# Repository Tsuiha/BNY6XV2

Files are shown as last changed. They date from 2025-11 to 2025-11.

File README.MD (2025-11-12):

# BNY6X V2

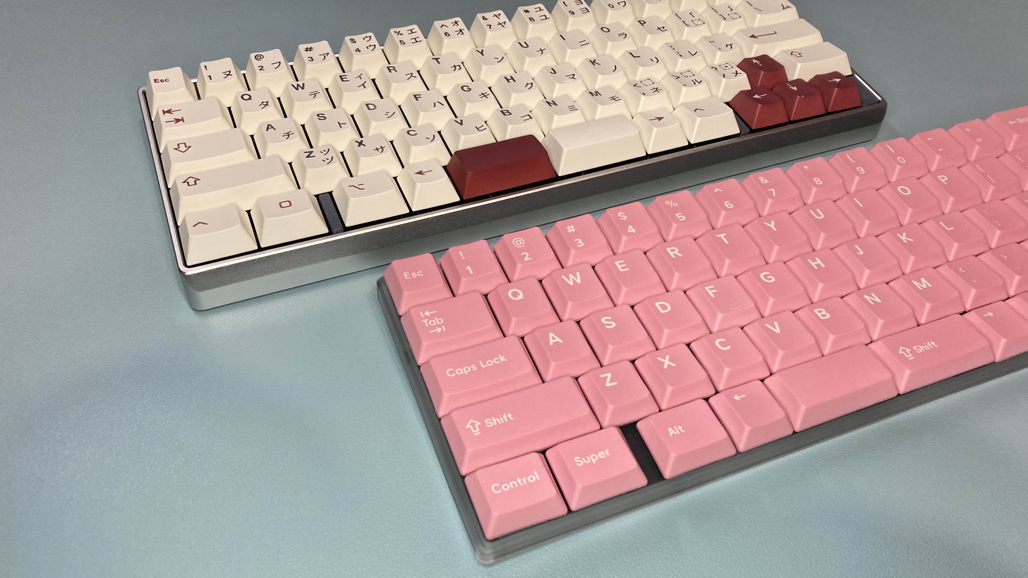
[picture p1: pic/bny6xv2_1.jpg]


「BNY6X V2」は2025年に製作した60%キーボードです。  
多親指キー＋矢印キー配列、MXとロープロに両対応、GH60互換ケース対応、の特徴があります。

---

## BNY6X V2 PCB

- **キー配列**
60%レイアウト  
親指キー、矢印キーを備えた最下行  

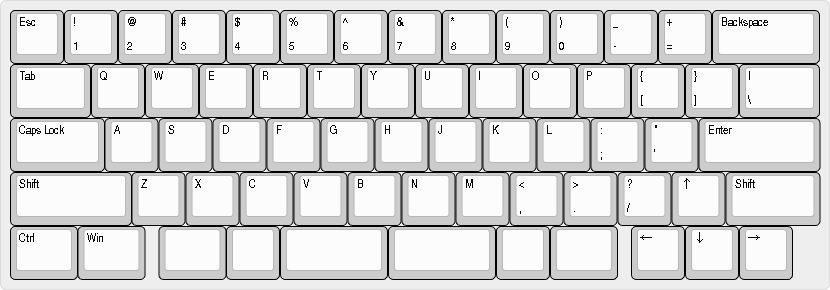
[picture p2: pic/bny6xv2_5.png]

[Keyboard Layout Editor](https://www.keyboard-layout-editor.com/)

- **対応マウント方式**
GH60互換設計で、6か所のネジ穴が設けられています。  
加えて外周に5か所の切り欠きが設けられており、独自のプレートマウントにも対応します。

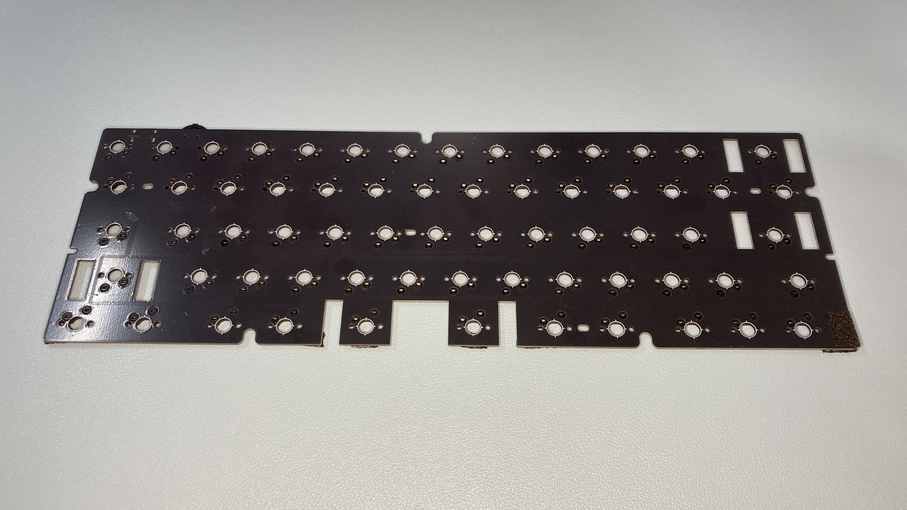
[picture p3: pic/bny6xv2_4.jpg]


- **対応スイッチ**
「Cherry MX 」または「KS-33B GateronLowProfile 3.0」に互換性のあるスイッチが使用できます。  
キースイッチはMX用ホットスワップソケットにてPCBに接続します。
ロープロ対応及び低背化のため基板は1.2mm を使用します。

- **サイドスイッチ**
背面type-C横には3方向（左、右、押し込み）のレバースイッチが取り付け可能です。  
既製品のGH60互換ケースに使用する際は、干渉するためレバースイッチは実装しない必要があります。

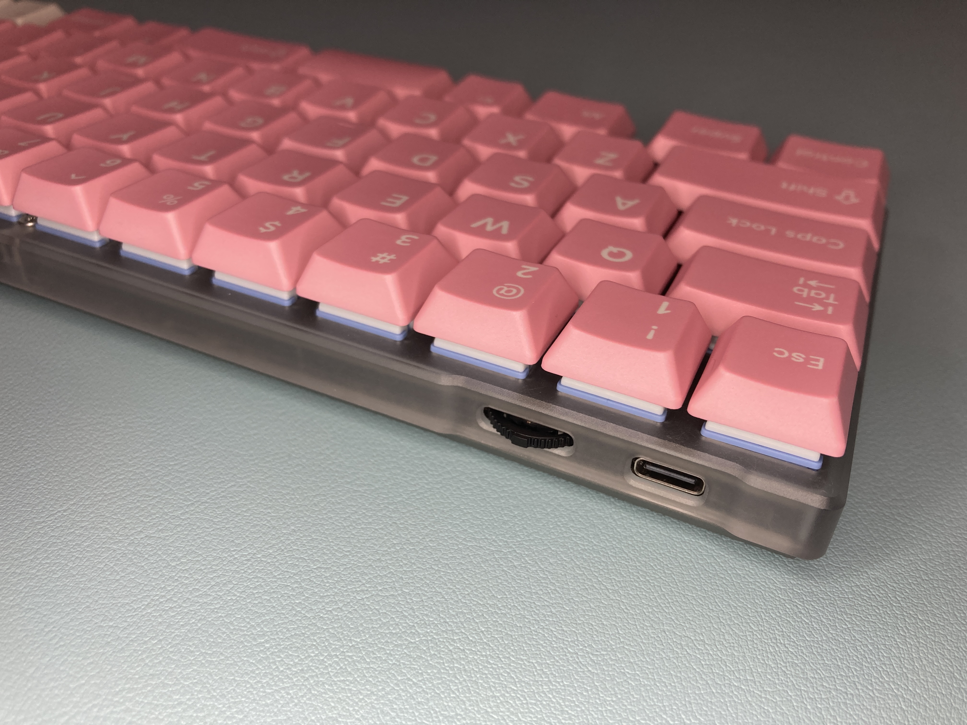
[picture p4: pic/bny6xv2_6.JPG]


- **対応スタビライザー**
プレートマウントのスタビライザーにのみ対応します。  
またMXスイッチの場合スタビライザー下が開いているため、ケース取り付け前に予めスタビライザー部のキーキャップは取り付けておく必要があります。

- **Firmware**
QMK Fimware, [BNY6X V2 codes](https://github.com/Tsuiha/vial-qmk/tree/vial/keyboards/0_tsuiha/bny6x_v2)

---

## BNY6X V2 typeT

1ピースでCNC加工を想定したGH60互換トレイケースです。

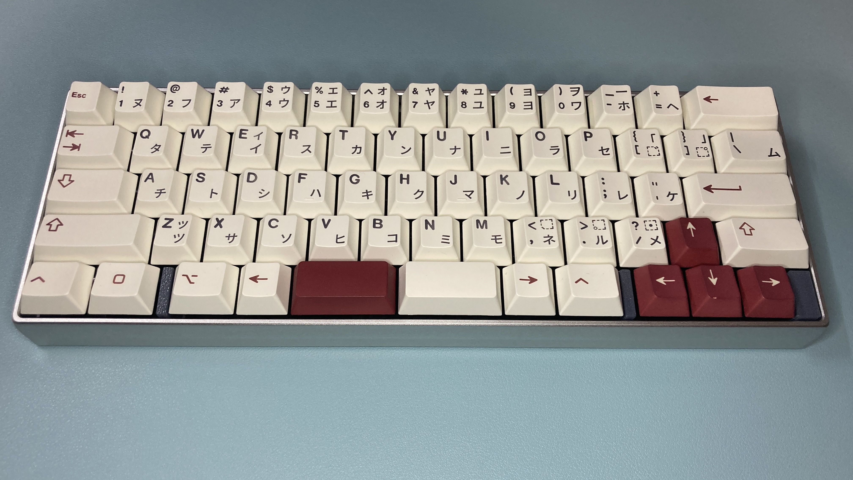
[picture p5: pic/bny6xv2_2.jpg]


- **マウント箇所**
左右4か所のみネジ受けを設けており、中央2か所は省いています。  
ねじ止めで位置を固定し、ボトムフォームで基板を保持する機構です。

- **フロントベゼル幅**
フロントトップのベゼルをカットし幅を抑えています。  
指付け根でのキー入力時に干渉しにくいです。

- **低背設計**
高さを抑えているため、手前部に背の高い実装部品や下付きソケットの基板の場合ケースに干渉する恐れがあります。

- **チルト角**
6度固定です。

- **type-C開口**
上方向に余裕があるため、手前部に基板の干渉がある場合、スタンドオフにスペーサを噛ませることで干渉を回避できます。  
また横方向のtype-C位置はGH60、Wootingの両方に対応します。

---

## BNY6X V2 typeL

BNY6X V2用に設計しました。  
2ピースでCNC加工を想定したKS33-Bスイッチ用のBNY6X V2 PCBケースです。

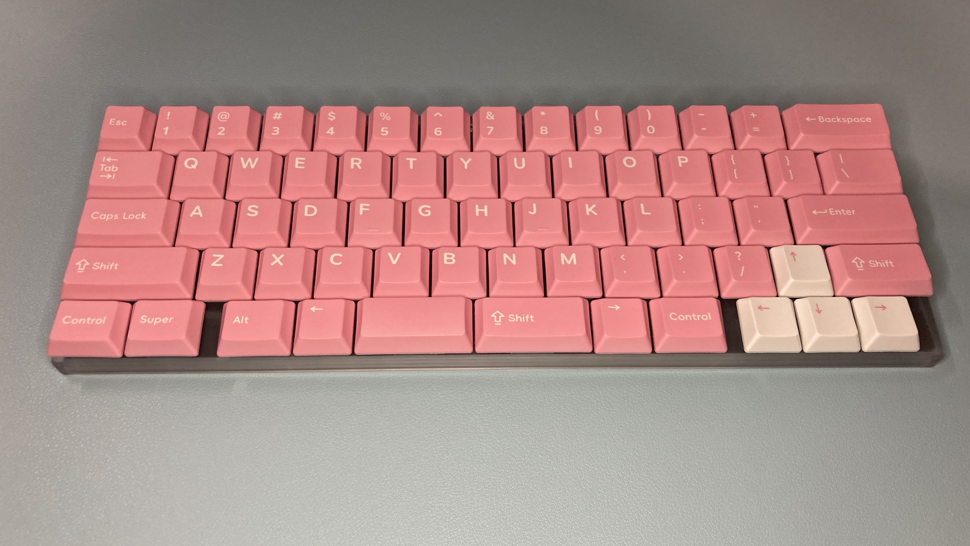
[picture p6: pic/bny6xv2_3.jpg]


- **対応スタビライザー**
Gateron KS-57　ロープロファイルスイッチ用スタビライザーに対応しています。

- **マウント方式**
BNY6X V2 PCBの切り欠き部を介しトップケースとボトムケースとをねじ止めしマウントします。

- **レバースイッチ**
背面はレバースイッチの実装に対応しています。

- **コンパクト設計**
高さとベゼル幅を抑えたコンパクトな外形です。

- **チルト角**
6度固定です。

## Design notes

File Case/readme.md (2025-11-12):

typeT:

 gh60 compatible case

typeL:

 original case for bny6x v2 with KS-33B switches

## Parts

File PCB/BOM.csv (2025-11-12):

bom | specification example of supplier
J1 | typeC receptacle topmount 16+8pins GCT USB4105-GF-A
U1 | STM STM32F072CBT6
U2 | onsemi CM1293A-04SO
U3 | 3.3V LDO SOT23 TI TLV77133PDBVR
side switch | sp3t TMHU27 Akitsukidenshi
boot switch | C&K spst pts526
C1,C3 | 1uF Capacitor 0603(1608m)
C2 | 4.7uF Capacitor 0603(1608m)
C4-C7 | 0.1uF Capacitor 0603(1608m)
R1,R2 | 5.1kohm Resistor 0603(1608m)
R3 | 10kohm Resistor 0603(1608m)

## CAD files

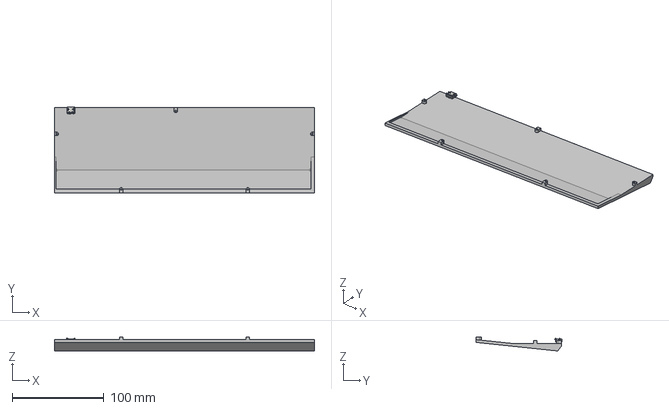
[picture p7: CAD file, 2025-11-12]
Case/typeL/bny6xv2_typeL_bot.step
283.4 x 93.9 x 15.2 mm

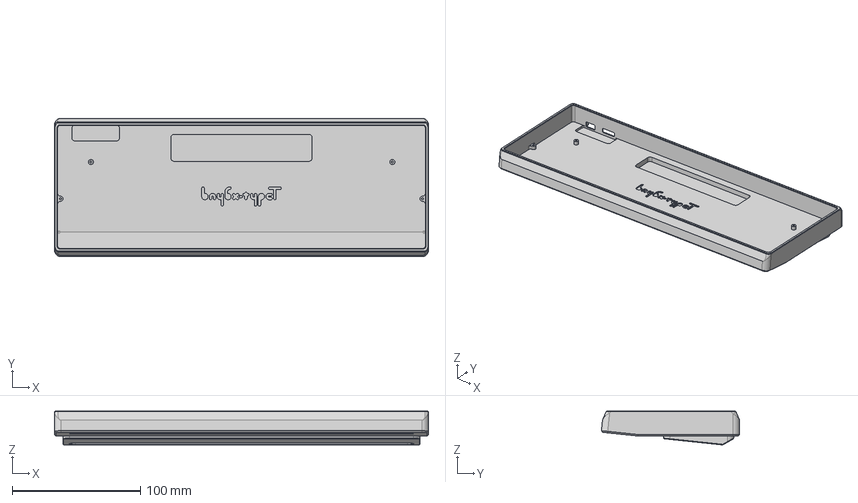
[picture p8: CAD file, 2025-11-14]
Case/typeT/bny6xv2_typeT_lever.step
291.3 x 107.7 x 26.5 mm

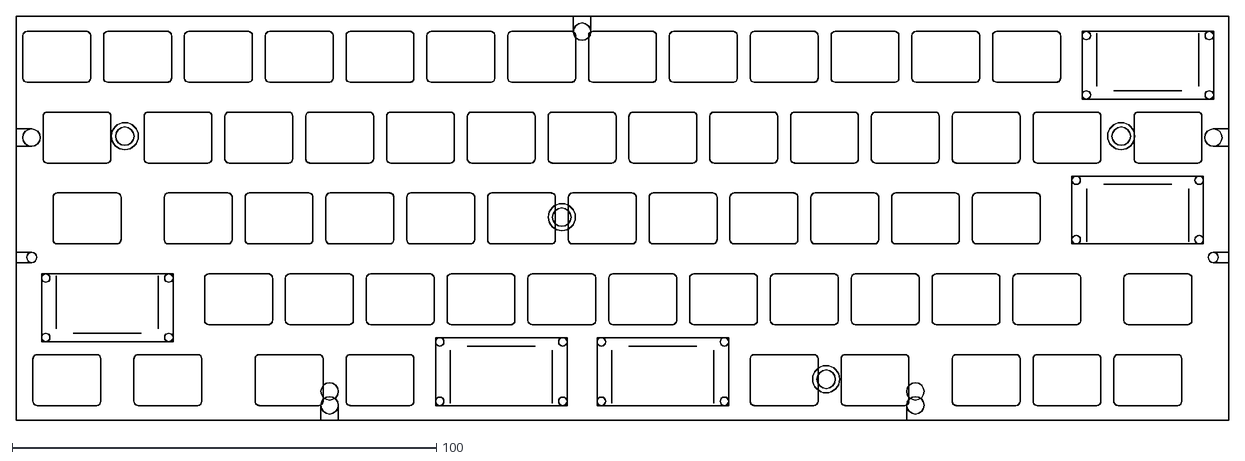
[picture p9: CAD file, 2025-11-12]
Plate/LP/bny6x2lp_plt_carvline.dxf
285.8 x 95.3

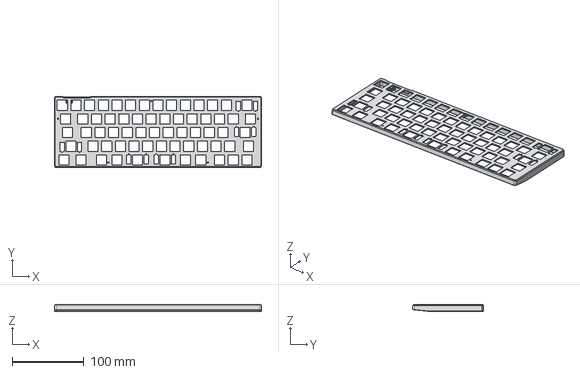
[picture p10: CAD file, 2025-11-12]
Case/typeL/bny6xv2_typeL_top.step
288.4 x 99.2 x 9.50 mm

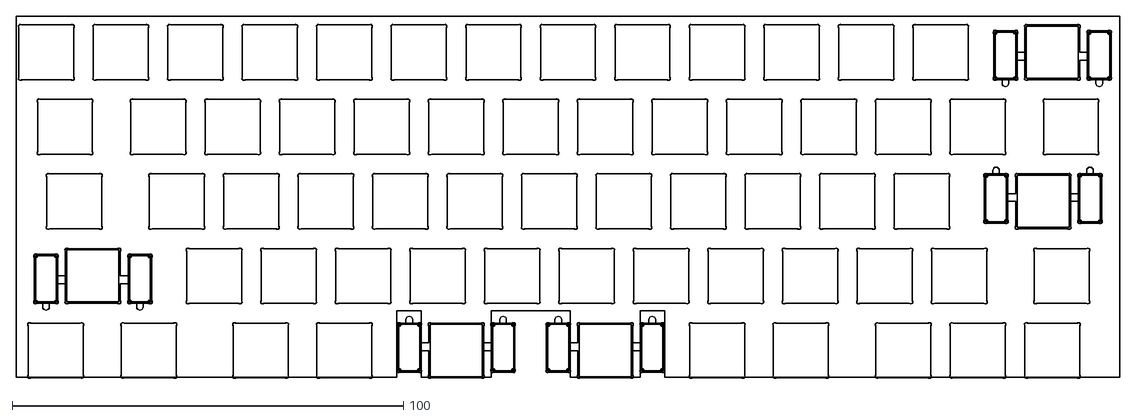
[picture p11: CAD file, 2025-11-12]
Plate/LP/bny6x2lp_plt_outline.dxf
282.2 x 92.6

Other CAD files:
Case/typeT/bny6xv2_typeT_gh60.step
Case/typeL/bny6xv2_typeL.f3d
Case/typeT/bny6xv2_typeT_gh60.f3d

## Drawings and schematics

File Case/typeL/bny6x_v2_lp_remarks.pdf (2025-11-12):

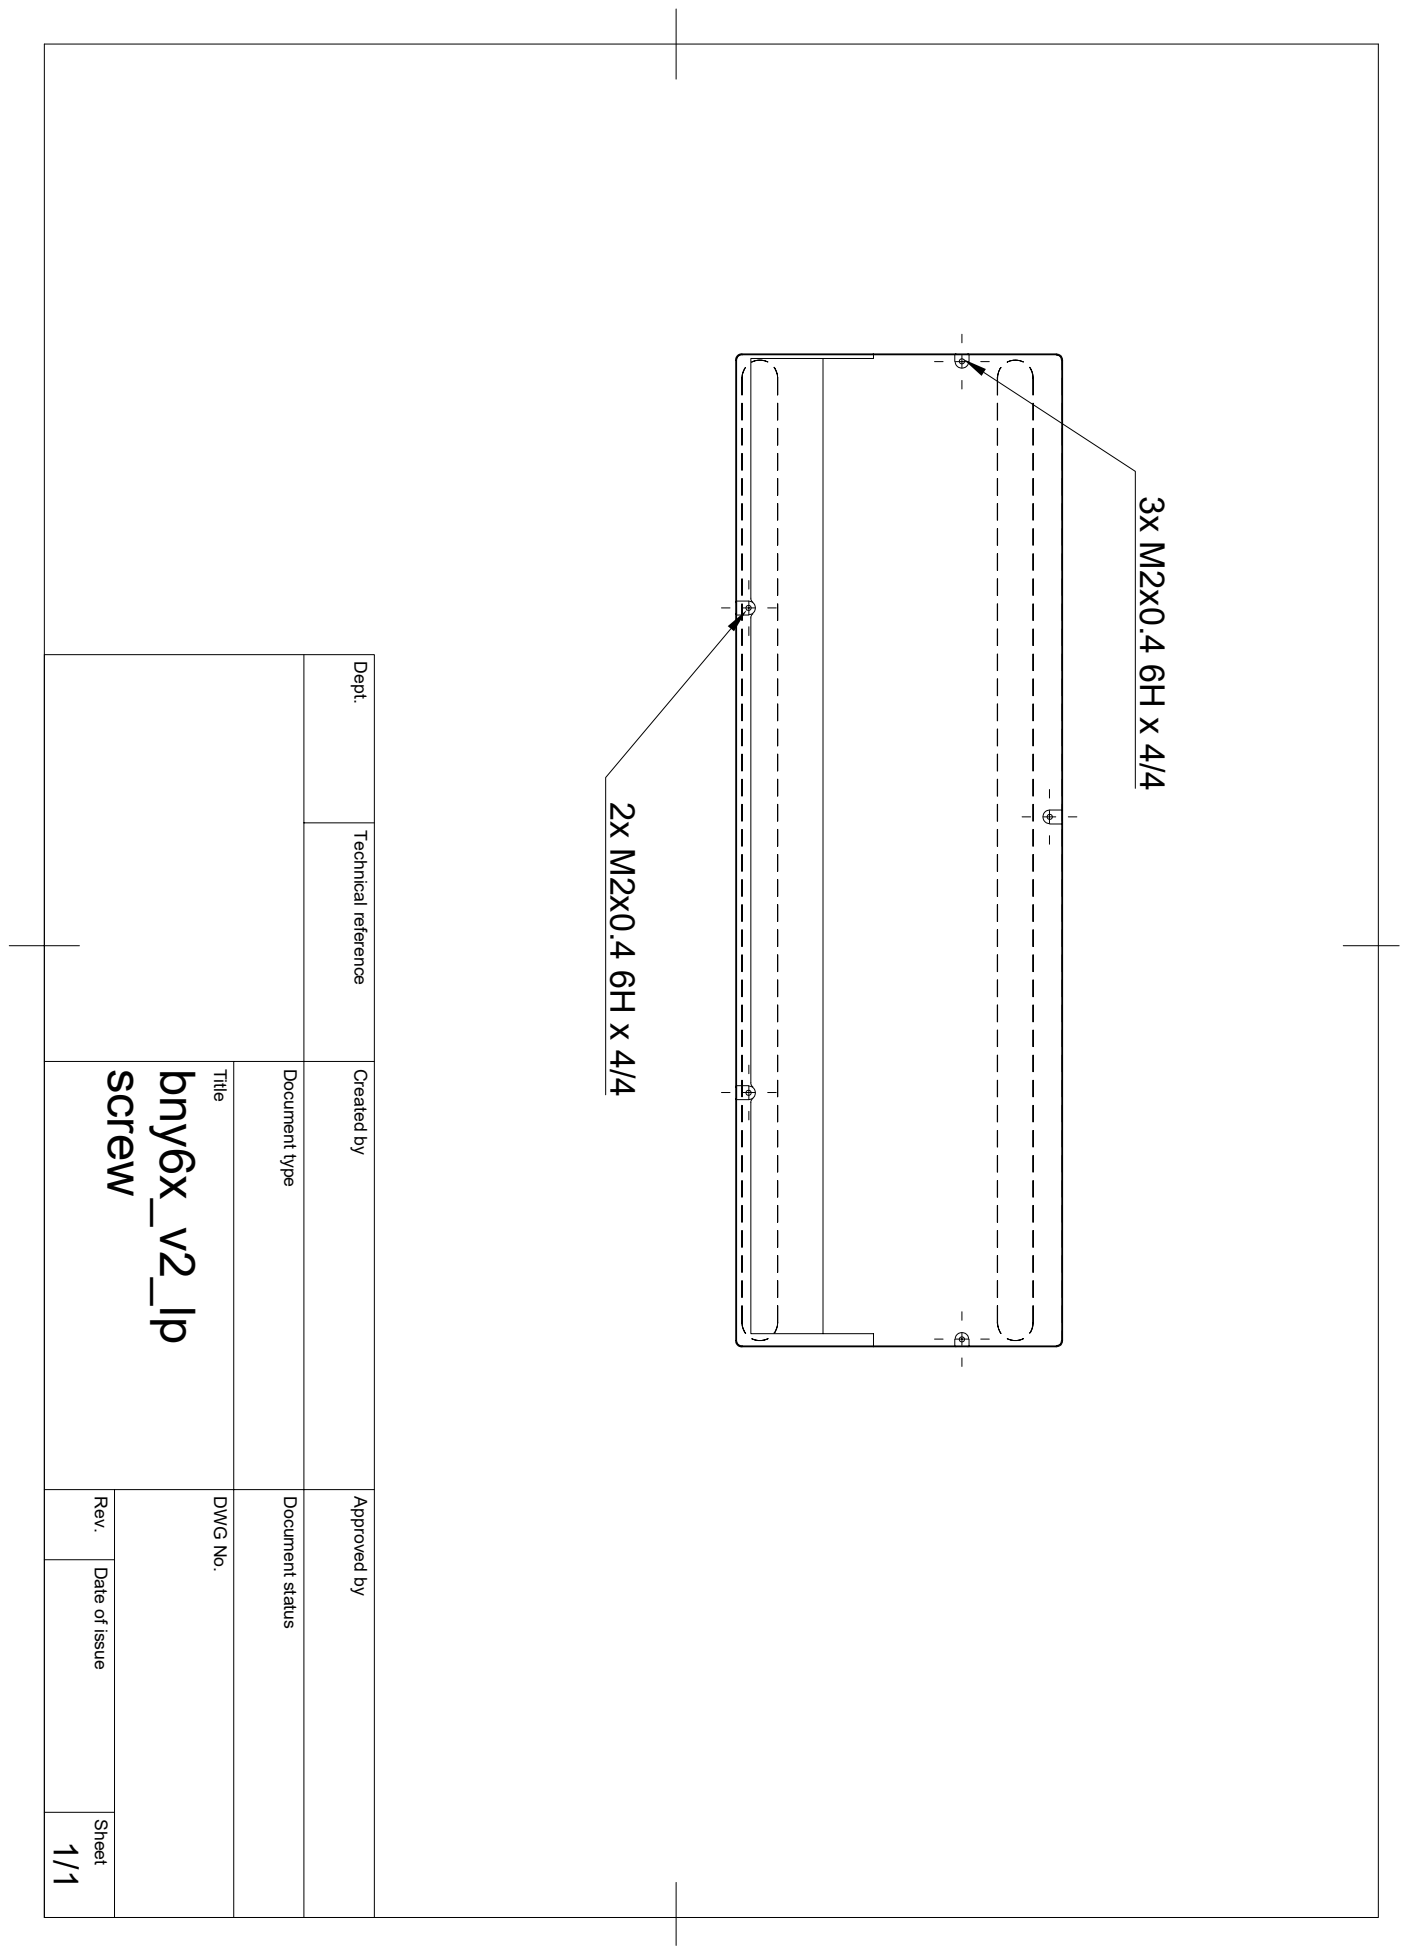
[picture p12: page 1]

Dept. Technical reference Created by Approved by Title DWG No. Document type Document status Rev. Date of issue Sheet 1/1 screw bny6x_v2_lp 3x M2x0.4 6H x 4/4 2x M2x0.4 6H x 4/4

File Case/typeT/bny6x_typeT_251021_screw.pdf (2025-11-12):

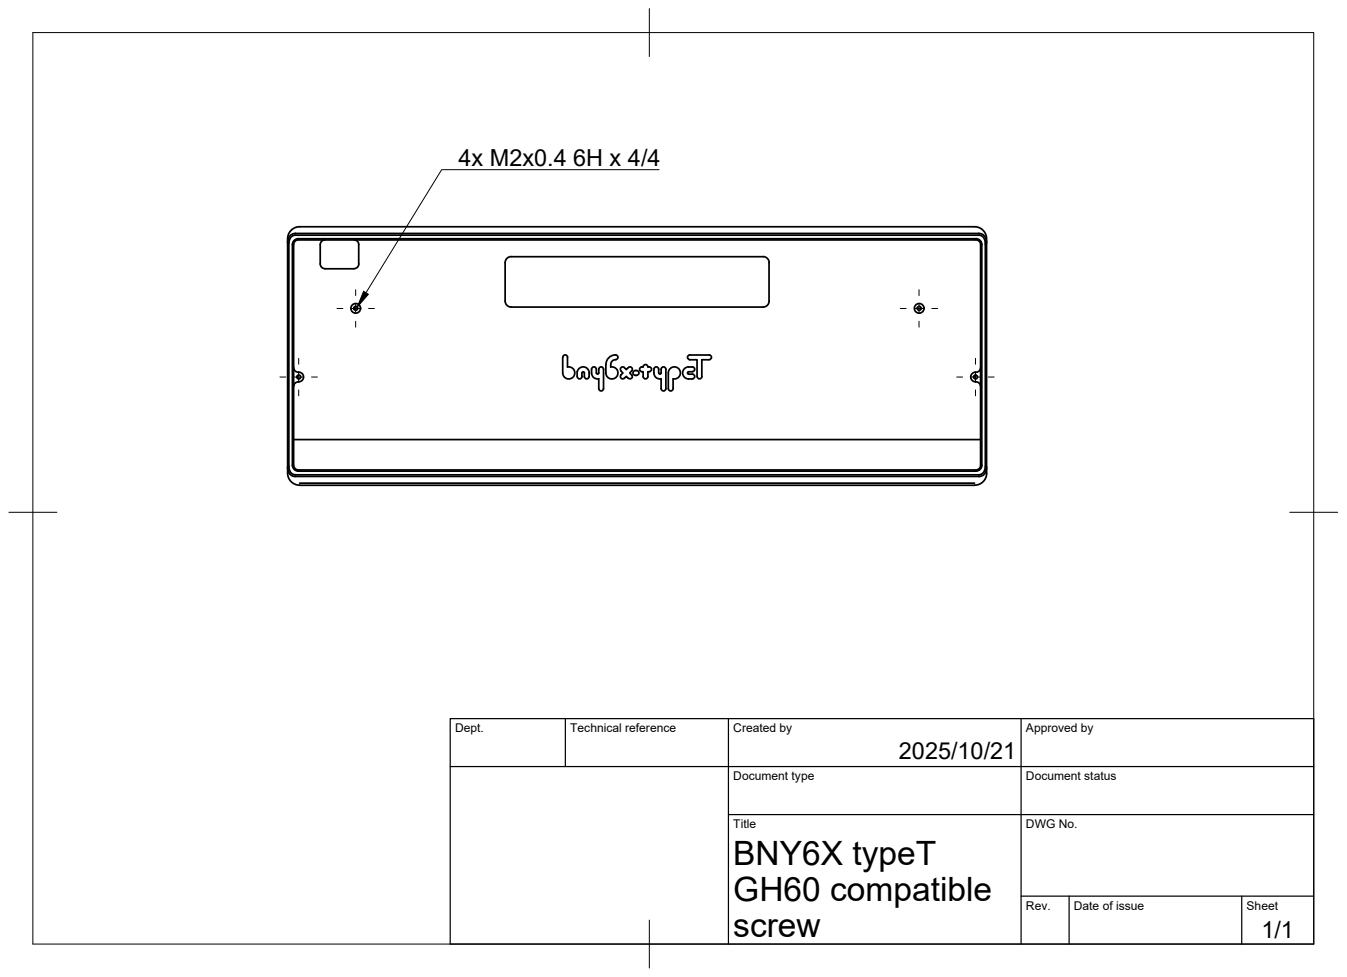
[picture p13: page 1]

Dept. | Technical reference | Created by 2025/10/21 | Approved by

Document type | Document status

Title BNY6X typeT GH60 compatible screw | DWG No.

Rev. | Date of issue | Sheet 1/1

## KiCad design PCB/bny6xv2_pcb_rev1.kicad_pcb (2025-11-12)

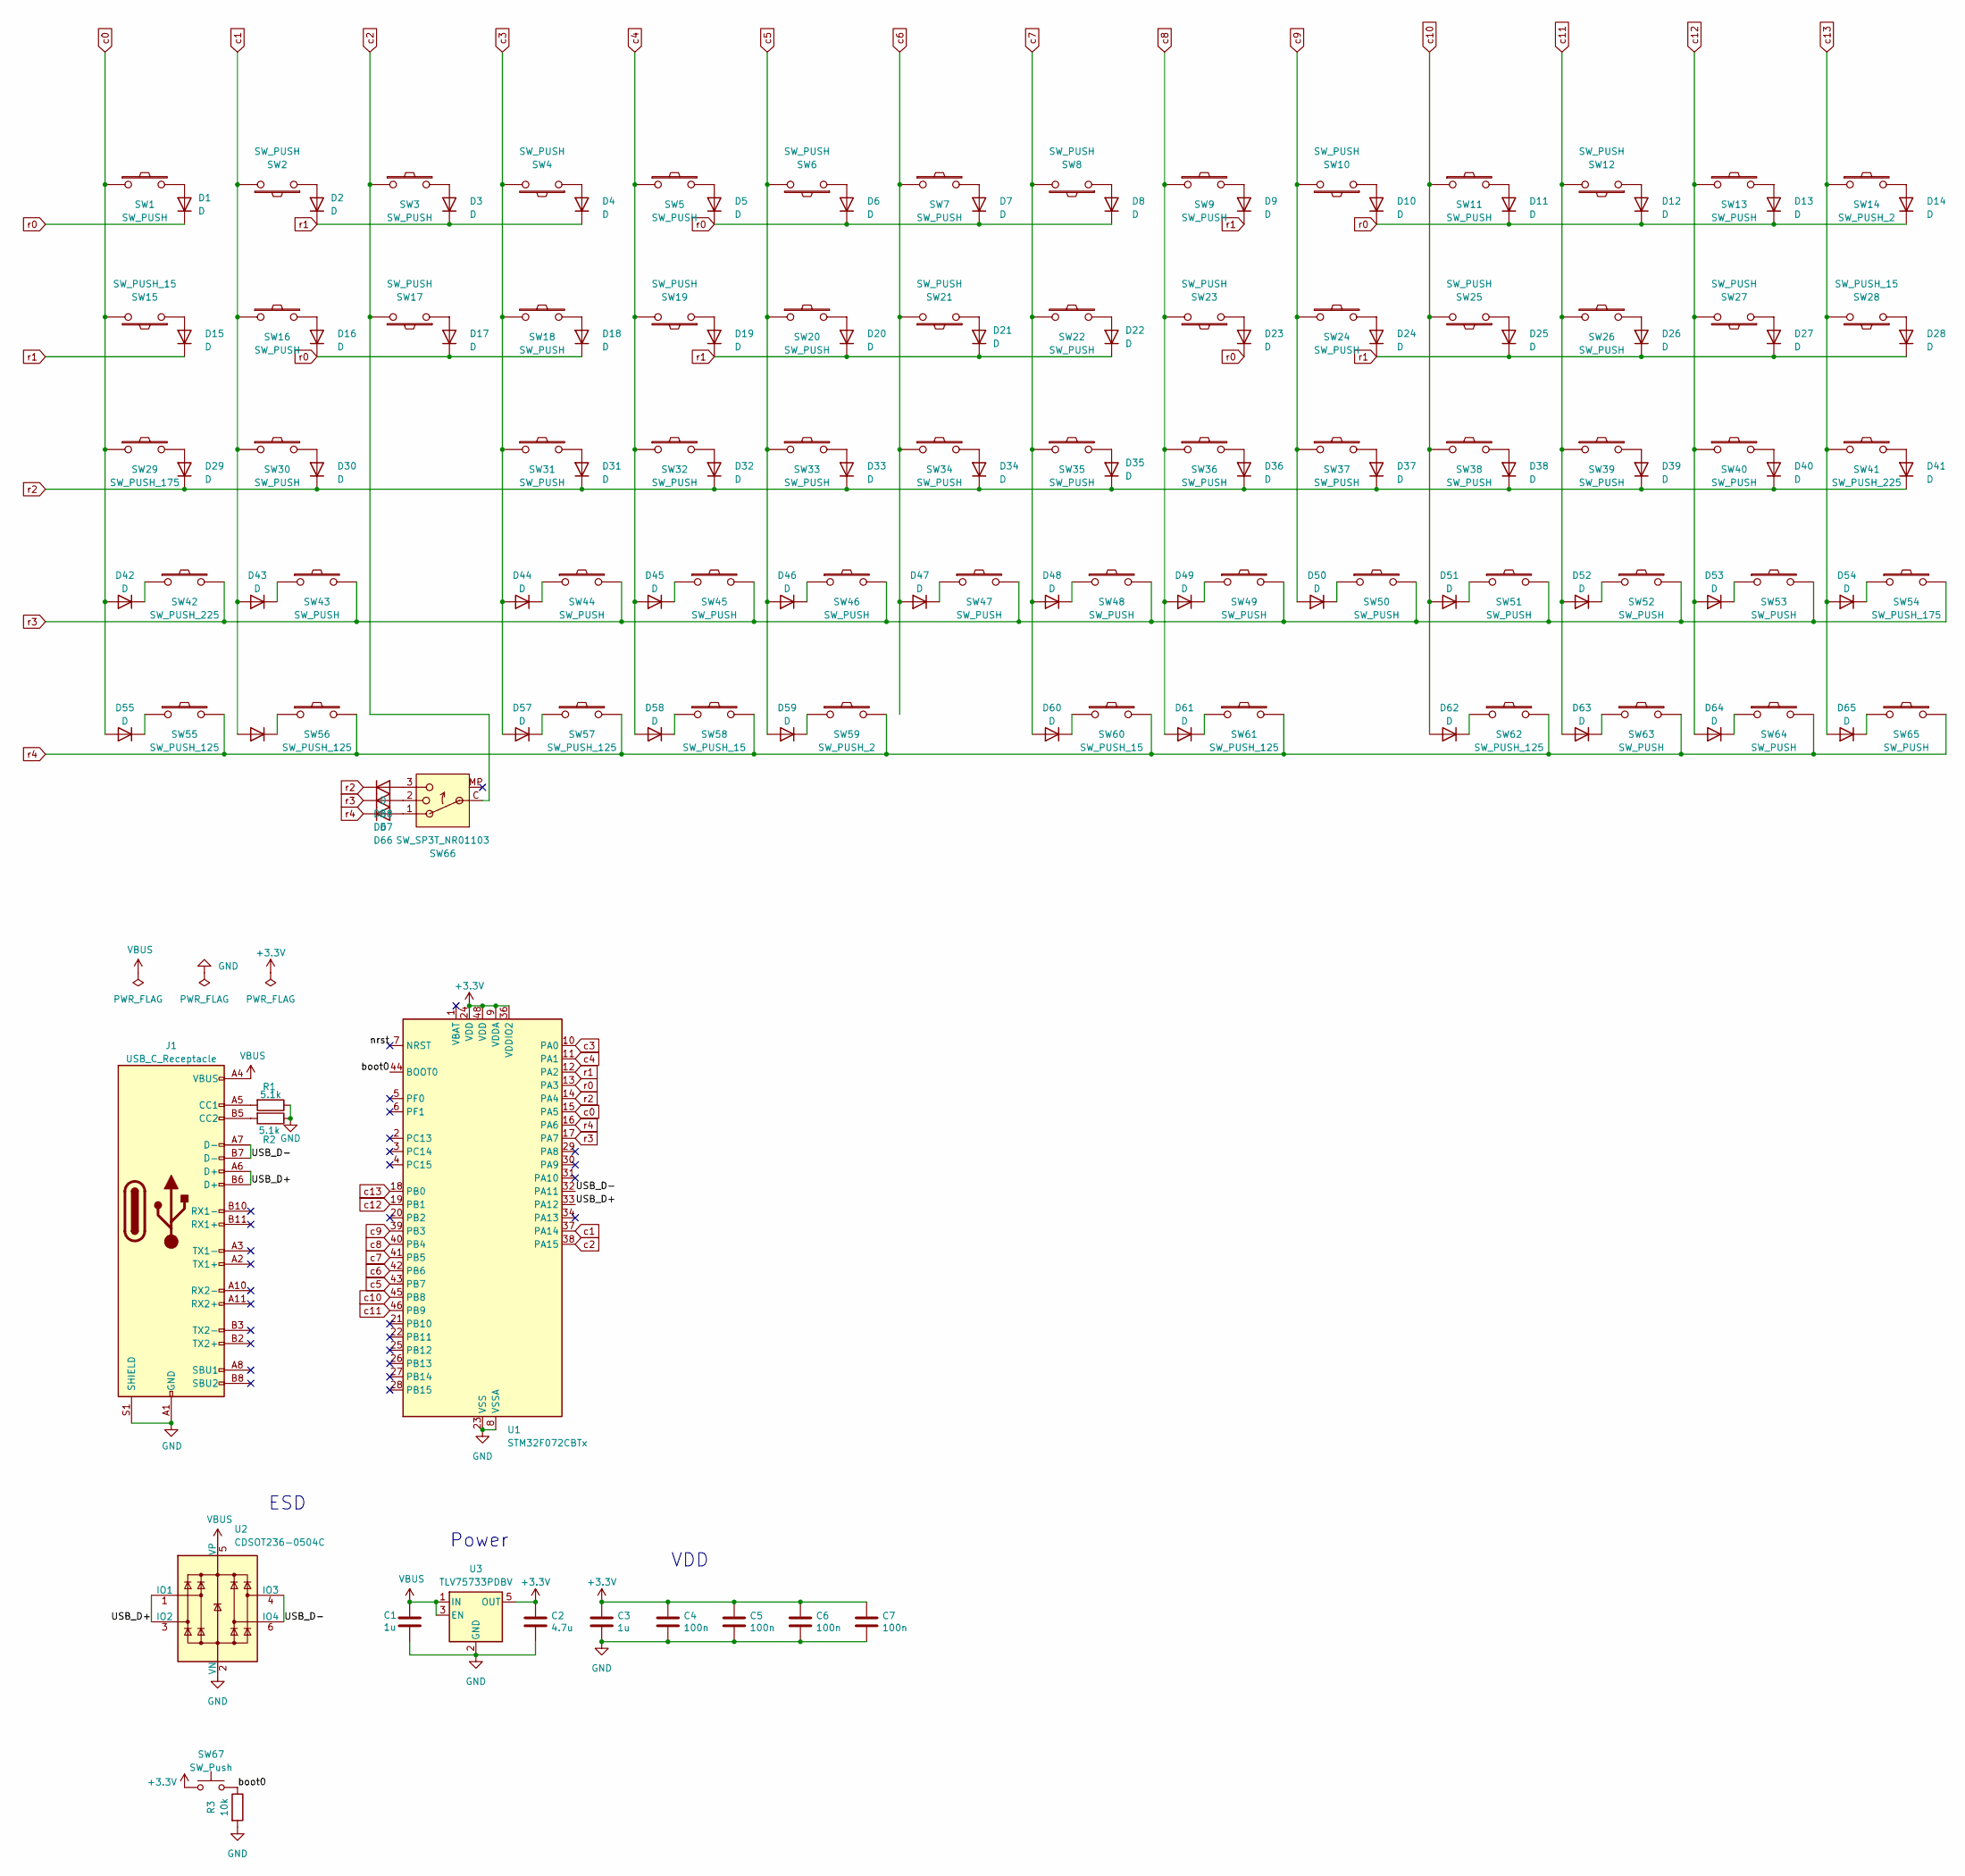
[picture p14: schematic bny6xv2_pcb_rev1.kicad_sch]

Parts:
C1, C3: 1u; C_0603_1608Metric
C2: 4.7u; C_0603_1608Metric
C4, C5, C6, C7: 100n; C_0603_1608Metric
D1, D2, D3, D4, D5, D6, D7, D8, D9, D10, D11, D12, D13, D14, D15, D16, D17, D18, D19, D20, D21, D22, D23, D24, D25, D26, D27, D28, D29, D30, D31, D32, D33, D34, D35, D36, D37, D38, D39, D40, D41, D42, D43, D44, D45, D46, D47, D48, D49, D50, D51, D52, D53, D54, D55, D56, D57, D58, D59, D60, D61, D62, D63, D64, D65, D66, D67, D68: D; Diode_SMD_noname
J1: USB_C_Receptacle; USB_C_Receptacle_HRO_TYPE-C-31-M-12_My
R1, R2: 5.1k; C_0603_1608Metric
R3: 10k; C_0603_1608Metric
SW1, SW2, SW3, SW4, SW5, SW6, SW7, SW8, SW9, SW10, SW11, SW12, SW13, SW16, SW17, SW18, SW19, SW20, SW21, SW22, SW23, SW24, SW25, SW26, SW27, SW30, SW31, SW32, SW33, SW34, SW35, SW36, SW37, SW38, SW39, SW40, SW43, SW44, SW45, SW46, SW47, SW48, SW49, SW50, SW51, SW52, SW53, SW63, SW64, SW65: SW_PUSH; GLPV3_1U
SW14, SW59: SW_PUSH_2; GLPV3_2u_r
SW15, SW28: SW_PUSH_15; GLPV3_1.5U
SW29: SW_PUSH_175; GLPV3_1.75U
SW41: SW_PUSH_225; GLPV3_2.25u
SW42: SW_PUSH_225; GLPV3_2.25u_r
SW54: SW_PUSH_175; MX_GLPV3_1.75U
SW55, SW56, SW57, SW62: SW_PUSH_125; GLPV3_1.25U
SW58: SW_PUSH_15; GLPV3_1U
SW60: SW_PUSH_15; GLPV3_2u_r
SW61: SW_PUSH_125; GLPV3_1U
SW66: SW_SP3T_NR01103; TMHU27
SW67: SW_Push; SW_SPST_SKQG_WithStem
U1: STM32F072CBTx; LQFP-48_7x7mm_P0.5mm
U2: CDSOT236-0504C; sot-23-6-USBESD
U3: TLV75733PDBV; SOT-23-5

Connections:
+3.3V: C2.1, C3.1, C4.1, C5.1, C6.1, C7.1, SW67.1, U1.9 (VDDA), U1.24 (VDD), U1.36 (VDDIO2), U1.48 (VDD), U3.5 (OUT)
/USB_D+: J1.A6 (D+), J1.B6 (D+), U1.33 (PA12), U2.1 (IO1), U2.3 (IO2)
/USB_D-: J1.A7 (D-), J1.B7 (D-), U1.32 (PA11), U2.4 (IO3), U2.6 (IO4)
/boot0: R3.1, SW67.2, U1.44 (BOOT0)
/nrst: U1.7 (NRST)
GND: C1.2, C2.2, C3.2, C4.2, C5.2, C6.2, C7.2, J1.A1 (GND), J1.A12 (GND), J1.B1 (GND), J1.B12 (GND), J1.S1 (SHIELD), R1.1, R2.1, R3.2, U1.8 (VSSA), U1.23 (VSS), U1.35 (VSS), U1.47 (VSS), U2.2 (VN), U3.2 (GND)
unnamed: D1.2 (A), SW1.2
unnamed: D2.2 (A), SW2.1
unnamed: D3.2 (A), SW3.2
unnamed: D4.2 (A), SW4.1
unnamed: D5.2 (A), SW5.2
unnamed: D6.2 (A), SW6.1
unnamed: D7.2 (A), SW7.2
unnamed: D8.2 (A), SW8.1
unnamed: D9.2 (A), SW9.2
unnamed: D10.2 (A), SW10.1
unnamed: D11.2 (A), SW11.2
unnamed: D12.2 (A), SW12.1
unnamed: D13.2 (A), SW13.2
unnamed: D14.2 (A), SW14.2
unnamed: D15.2 (A), SW15.1
unnamed: D16.2 (A), SW16.2
unnamed: D17.2 (A), SW17.1
unnamed: D18.2 (A), SW18.2
unnamed: D19.2 (A), SW19.1
unnamed: D20.2 (A), SW20.2
unnamed: D21.2 (A), SW21.1
unnamed: D22.2 (A), SW22.2
unnamed: D23.2 (A), SW23.1
unnamed: D24.2 (A), SW24.2
unnamed: D25.2 (A), SW25.1
unnamed: D26.2 (A), SW26.2
unnamed: D27.2 (A), SW27.1
unnamed: D28.2 (A), SW28.1
unnamed: D29.2 (A), SW29.2
unnamed: D30.2 (A), SW30.2
unnamed: D31.2 (A), SW31.2
unnamed: D32.2 (A), SW32.2
unnamed: D33.2 (A), SW33.2
unnamed: D34.2 (A), SW34.2
unnamed: D35.2 (A), SW35.2
unnamed: D36.2 (A), SW36.2
unnamed: D37.2 (A), SW37.2
unnamed: D38.2 (A), SW38.2
unnamed: D39.2 (A), SW39.2
unnamed: D40.2 (A), SW40.2
unnamed: D41.2 (A), SW41.2
unnamed: D42.1 (K), SW42.1
unnamed: D43.1 (K), SW43.1
unnamed: D44.1 (K), SW44.1
unnamed: D45.1 (K), SW45.1
unnamed: D46.1 (K), SW46.1
unnamed: D47.1 (K), SW47.1
unnamed: D48.1 (K), SW48.1
unnamed: D49.1 (K), SW49.1
unnamed: D50.1 (K), SW50.1
unnamed: D51.1 (K), SW51.1
unnamed: D52.1 (K), SW52.1
unnamed: D53.1 (K), SW53.1
unnamed: D54.1 (K), SW54.1
unnamed: D55.1 (K), SW55.1
unnamed: D56.1 (K), SW56.1
unnamed: D57.1 (K), SW57.1
unnamed: D58.1 (K), SW58.1
unnamed: D59.1 (K), SW59.1
unnamed: D60.1 (K), SW60.1
unnamed: D61.1 (K), SW61.1
unnamed: D62.1 (K), SW62.1
unnamed: D63.1 (K), SW63.1
unnamed: D64.1 (K), SW64.1
unnamed: D65.1 (K), SW65.1
unnamed: D66.2 (A), SW66.1
unnamed: D67.2 (A), SW66.2
unnamed: D68.2 (A), SW66.3
unnamed: J1.A5 (CC1), R1.2
unnamed: J1.B5 (CC2), R2.2
VBUS: C1.1, J1.A4 (VBUS), J1.A9 (VBUS), J1.B4 (VBUS), J1.B9 (VBUS), U2.5 (VP), U3.1 (IN), U3.3 (EN)
c0: D42.2 (A), D55.2 (A), SW1.1, SW15.2, SW29.1, U1.15 (PA5)
c1: D43.2 (A), D56.2 (A), SW2.2, SW16.1, SW30.1, U1.37 (PA14)
c2: SW3.1, SW17.2, SW66.C (Common), U1.38 (PA15)
c3: D44.2 (A), D57.2 (A), SW4.2, SW18.1, SW31.1, U1.10 (PA0)
c4: D45.2 (A), D58.2 (A), SW5.1, SW19.2, SW32.1, U1.11 (PA1)
c5: D46.2 (A), D59.2 (A), SW6.2, SW20.1, SW33.1, U1.43 (PB7)
c6: D47.2 (A), SW7.1, SW21.2, SW34.1, U1.42 (PB6)
c7: D48.2 (A), D60.2 (A), SW8.2, SW22.1, SW35.1, U1.41 (PB5)
c8: D49.2 (A), D61.2 (A), SW9.1, SW23.2, SW36.1, U1.40 (PB4)
c9: D50.2 (A), SW10.2, SW24.1, SW37.1, U1.39 (PB3)
c10: D51.2 (A), D62.2 (A), SW11.1, SW25.2, SW38.1, U1.45 (PB8)
c11: D52.2 (A), D63.2 (A), SW12.2, SW26.1, SW39.1, U1.46 (PB9)
c12: D53.2 (A), D64.2 (A), SW13.1, SW27.2, SW40.1, U1.19 (PB1)
c13: D54.2 (A), D65.2 (A), SW14.1, SW28.2, SW41.1, U1.18 (PB0)
r0: D1.1 (K), D5.1 (K), D6.1 (K), D7.1 (K), D8.1 (K), D10.1 (K), D11.1 (K), D12.1 (K), D13.1 (K), D14.1 (K), D16.1 (K), D17.1 (K), D18.1 (K), D23.1 (K), U1.13 (PA3)
r1: D2.1 (K), D3.1 (K), D4.1 (K), D9.1 (K), D15.1 (K), D19.1 (K), D20.1 (K), D21.1 (K), D22.1 (K), D24.1 (K), D25.1 (K), D26.1 (K), D27.1 (K), D28.1 (K), U1.12 (PA2)
r2: D29.1 (K), D30.1 (K), D31.1 (K), D32.1 (K), D33.1 (K), D34.1 (K), D35.1 (K), D36.1 (K), D37.1 (K), D38.1 (K), D39.1 (K), D40.1 (K), D41.1 (K), D68.1 (K), U1.14 (PA4)
r3: D67.1 (K), SW42.2, SW43.2, SW44.2, SW45.2, SW46.2, SW47.2, SW48.2, SW49.2, SW50.2, SW51.2, SW52.2, SW53.2, SW54.2, U1.17 (PA7)
r4: D66.1 (K), SW55.2, SW56.2, SW57.2, SW58.2, SW59.2, SW60.2, SW61.2, SW62.2, SW63.2, SW64.2, SW65.2, U1.16 (PA6)

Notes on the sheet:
Power
ESD
VDD

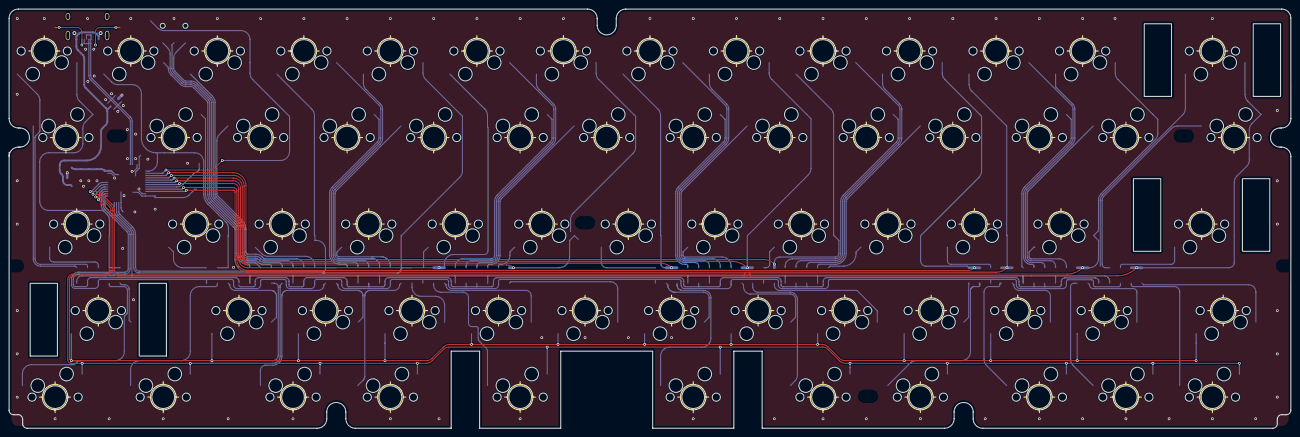
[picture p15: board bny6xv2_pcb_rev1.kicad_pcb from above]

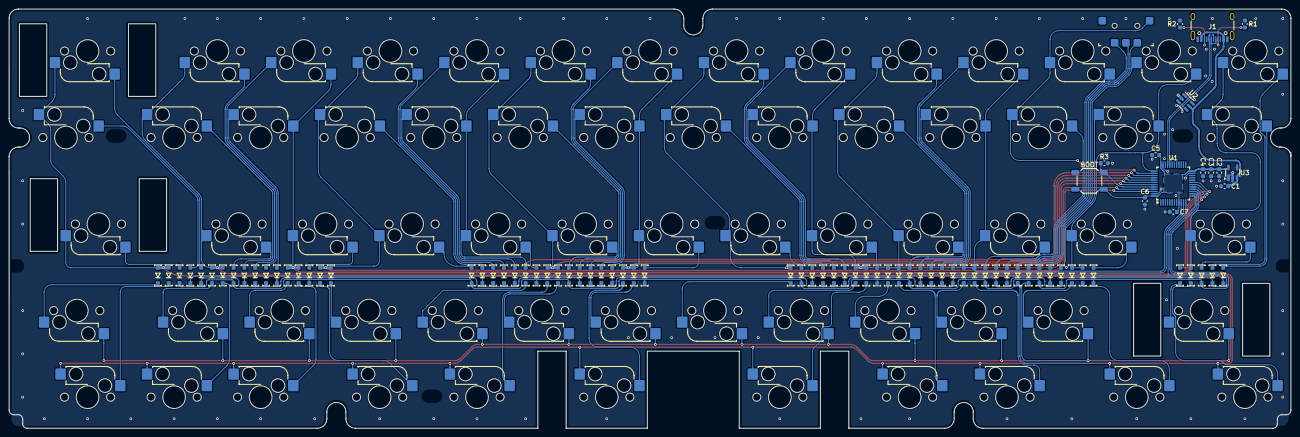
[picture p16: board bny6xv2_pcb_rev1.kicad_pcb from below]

Board: 2 copper layers, 282.2 x 92.3 mm, 149 parts (16 on the bottom side), 95 nets.
